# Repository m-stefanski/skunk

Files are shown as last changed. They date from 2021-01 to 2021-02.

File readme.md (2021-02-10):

# Skunks

Skunks (Polish for Skunk) is a small air quality meter aimed for use in developing countries, home projects and in every place where affordable air quality meter might be useful. 

It is designed to be cheap and easy to make from over-the-counter parts.

## Capabilities

Skunk can measure following air parameters:

* PM 2,5
* Temperature
* Humidity
* Pressure

Results are available as a website presented when user connects to a WiFi network the device is broadcasting. It is also possible to configure skunk to connect to any available 2.4 GHz WiFi network and view its results there.

## Hardware

* [WeMOS D1 mini](https://www.wemos.cc/en/latest/d1/d1_mini.html) - for CPU / Memory / IO and WiFi capabilities
* [GP2Y1010AU0F](https://www.sharpsde.com/products/optoelectronic-components/model/GP2Y1010AU0F/) - dust sensor from Sharp
* [BME280](https://www.bosch-sensortec.com/products/environmental-sensors/humidity-sensors-bme280/) - temprerature, humidity and air pressure sensor from BOSH

Data sheets for used components are available in [datasheets](/datasheets) directory.

## Designs

All sources are available in [src](/src) directory. Web content needs to be converted to `.h` files:

```
git clone https://github.com/Jamesits/bin2array.git 
cd ./src/web_content
find . -iname "*.*"  -type f -exec python3 ./../../bin2array/bin2array.py '{}' -O ./../'{}'.h \;
```

BB overview is shown below.

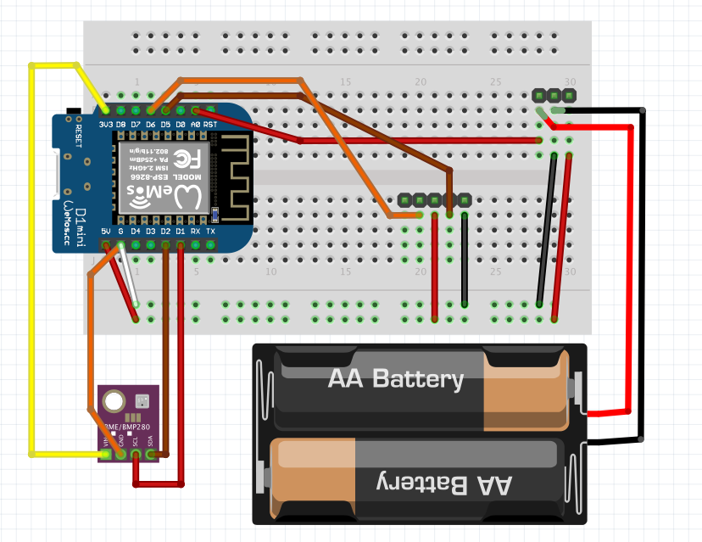
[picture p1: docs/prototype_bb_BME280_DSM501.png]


Electrical schematics:

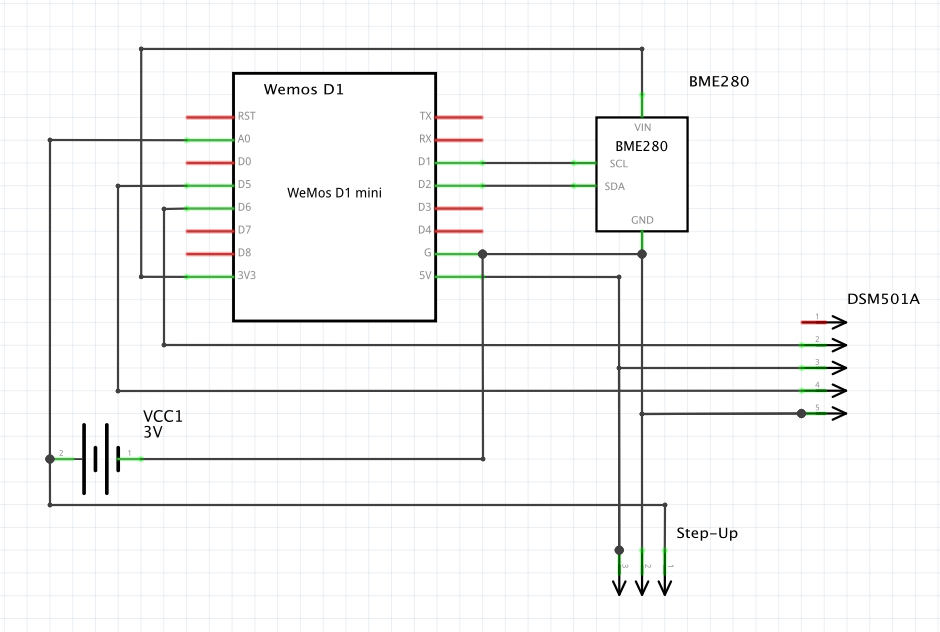
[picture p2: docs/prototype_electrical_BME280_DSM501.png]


PCB:

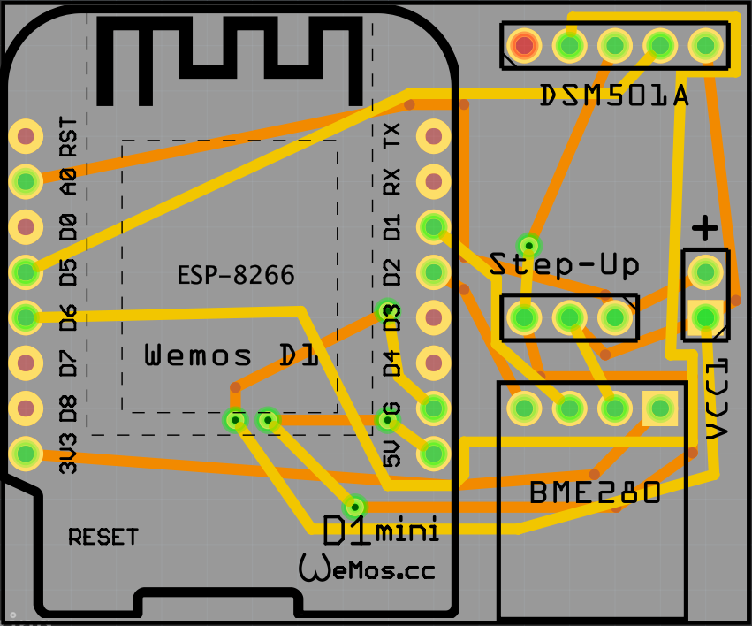
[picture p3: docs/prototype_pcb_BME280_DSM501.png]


And very, VERY unholy real photos of firts prototype:

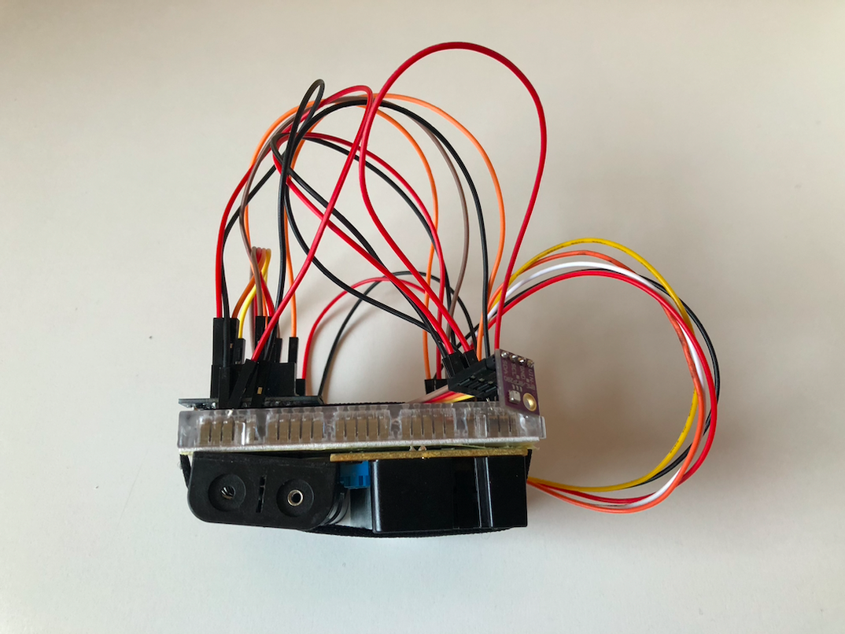
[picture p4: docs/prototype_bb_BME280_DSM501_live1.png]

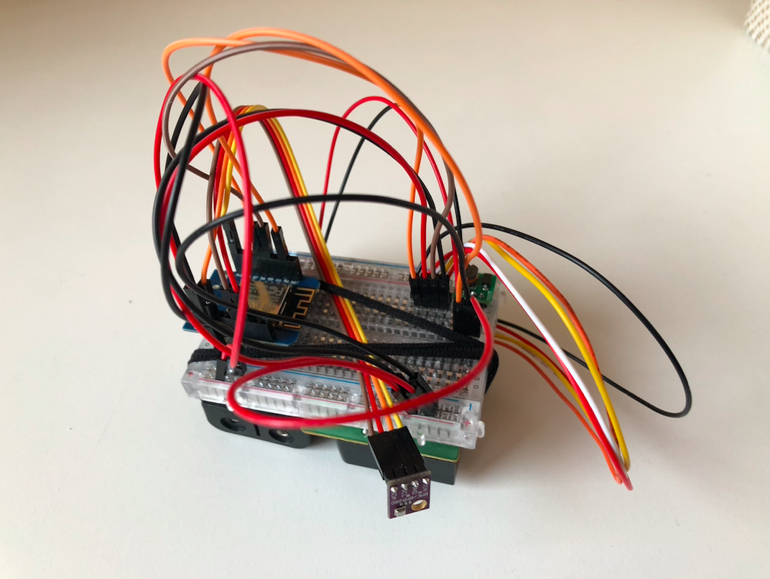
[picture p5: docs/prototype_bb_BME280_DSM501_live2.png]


All hardware designs are stored in [board](/board) directory. Old iterations are kept as well, should the hardware change.

Skunk icon is stored in [icon](/icon) directory. It is a skunk glyph from [OpenMoji](https://openmoji.org) with added background. Due to limited space it is exported as 4-bit grayscale 180x180 px.

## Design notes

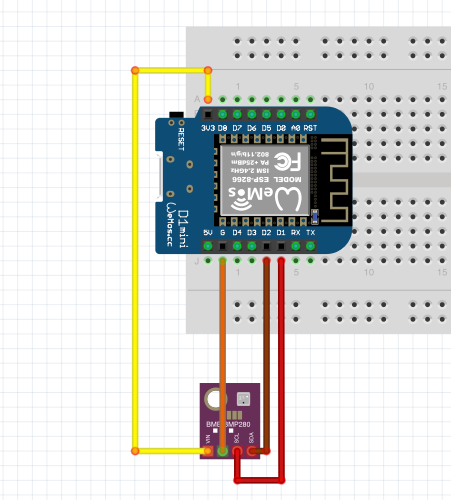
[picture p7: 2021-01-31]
docs/prototype_bb.png

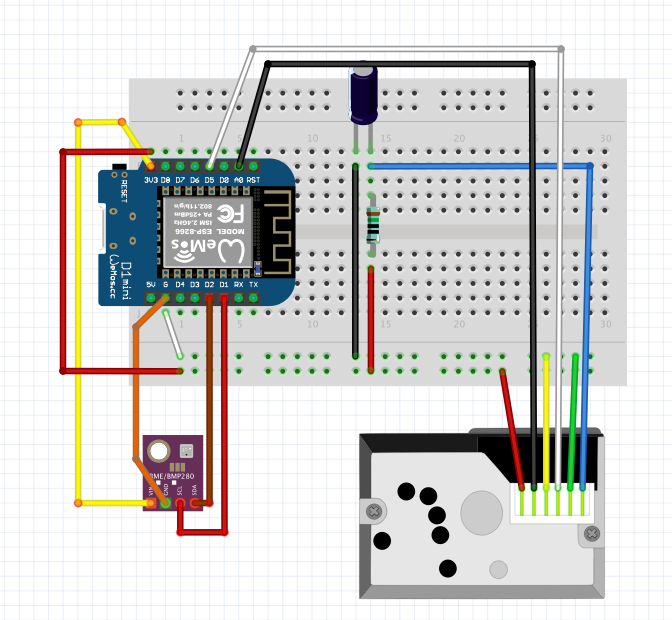
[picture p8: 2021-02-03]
docs/prototype_bb_BME280_GP2Y1010AU0F.png

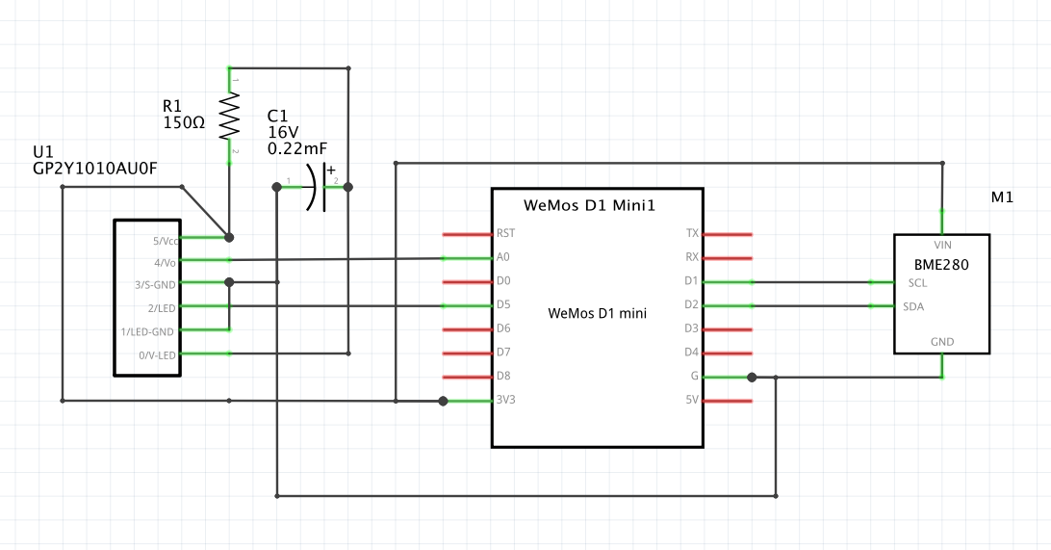
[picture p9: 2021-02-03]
docs/prototype_electrical_BME280_GP2Y1010AU0F.png

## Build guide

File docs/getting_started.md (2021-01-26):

# Running first code

In case of my device (MacOS Big Sur), driver was alread embedded in os, and port was `/dev/cu.usbserial-1420`

To program, esptool was used:

```
sudo pip3 install esptool
sudo esptool.py -p /dev/cu.usbserial-1420 erase_flash
sudo esptool.py -p /dev/cu.usbserial-1420 --baud 460800 write_flash --flash_size=detect 0 ./bin/esp8266-20200911-v1.13.bin
```

To push latest code and run:

```
sudo pip3 install mpy-repl-tool
sudo python3 -m there push ./src/*.py ./ --verbose
sudo python3 -m there -i 
```

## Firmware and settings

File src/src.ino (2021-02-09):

#include <Wire.h>
#include <Adafruit_Sensor.h>
#include <Adafruit_BME280.h>

#include <ESP8266WiFi.h>
#include <DNSServer.h>
#include <ESP8266WebServer.h>
#include "DSM501.h"
#include <Ticker.h>
#include <EEPROM.h>

#define DSM501_PM2_5 D5 // pin 4 - Vout1 - over 2.5 um
#define DSM501_PM1_0 D6 // pin 2 - Vout2 - over 1 um
#define PIN_BATTERY_VOLTAGE A0

#define SAMPLE_TIME_DSM510 30
#define SAMPLE_TIME_BME280 2
#define SAMPLE_TIME_VOLTAGE 1

const char *ssid = "skunks"; // network name
const char *hostname = "skunks"; // dns domain name
IPAddress apIP(192, 168, 4, 1); // ip address

DNSServer dnsServer;
Adafruit_BME280 bme;
DSM501 dsm501;
ESP8266WebServer server(80);
Ticker timer_voltage;
Ticker timer_bme280;

int pm25 = 0;
float battery_voltage = 0;
float temperature = 0;
float humidity = 0;
float pressure = 0;

void setup() {
  Serial.begin(115200);
  cls();
  Serial.println("[app] Starting");
  setup_eeprom(512);
  setup_voltage();
  setup_bme280();
  setup_dsm501a();
  setup_ap();
  setup_dns();
  setup_web();
  Serial.println("[app] Skunks ready");
}

void write_string_to_eeprom(int pos, String str) {
  for (int i = 0; i < str.length(); ++i)
    {
      EEPROM.write(i + pos, str[i]);
    }
  EEPROM.write(str.length(), 0xFF);
  EEPROM.commit();
  Serial.println(String("[eeprom] Wrote ") + str.length() + " bytes from pos: " + pos);
}

String read_string_from_eeprom(int pos) {
  String str;
  int pos_act = pos;
  uint8_t next_char = 0;
  while (true) {
    next_char = EEPROM.read(pos_act);
    if (next_char != 0xFF){
    str += char(next_char);
    pos_act++;
  }
    else {
      Serial.println(String("[eeprom] Read ") + str.length() + " bytes from pos: " + pos + ": " + str);
  return str;
}
  }
}

void loop() {
  server.handleClient();
  dnsServer.processNextRequest();
  read_dsm501a();
}

void cls() {
  Serial.write(27);
  Serial.print("[2J");
  Serial.write(27);
  Serial.print("[H");
}

void setup_eeprom(int size) {
  Serial.println("[eeprom] Initializing ...");
  EEPROM.begin(size);
  delay(50); // without a delay eeprom r/w may result in an error
  Serial.println(String("[eeprom] Initialized size: ") + size);
}

void setup_bme280() {
  Serial.println("[bme280] Setting up...");
  bool status;
  status = bme.begin(0x76);
  if (!status) {
    Serial.println("[bme280] ERROR: device not found!");
    while (1); // stopping the program
  }
  Serial.println("[bme280] Setting repeated measures");
  timer_bme280.attach(SAMPLE_TIME_BME280, read_bme280);
  Serial.println("[bme280] Ready");
}

void setup_dsm501a() {
  Serial.println("[dsm501a] Setting up...");
  dsm501.begin(DSM501_PM1_0, DSM501_PM2_5, SAMPLE_TIME_DSM510);
  Serial.println("[dsm501a] Ready");
}

void setup_voltage() {
  Serial.println("[volt] Setting up...");
  timer_voltage.attach(SAMPLE_TIME_VOLTAGE, read_voltage);
  Serial.println("[volt] Ready");
}

void read_dsm501a(){
  if (dsm501.update())
  { 
    pm25 = dsm501.getConcentration();
    Serial.println(String("[dsm501a] Read: PM1: ") + dsm501.getParticleCount(0) + ", PM2.5: " + dsm501.getParticleCount(1) + ", concentration: " + dsm501.getConcentration());
  } 
}

void read_bme280(){
  temperature = bme.readTemperature();
  pressure = bme.readPressure() / 100.0F;
  humidity = bme.readHumidity();
  Serial.println(String("[bme280] Read: temperature: ") + temperature  + "*C, humidity: " + humidity + "%, pressure: " + pressure + " hPa");
}

void read_voltage() {
  float calculated_voltage = analogRead(PIN_BATTERY_VOLTAGE) / 1024.0F * 3.3;
  battery_voltage = calculated_voltage;
  Serial.println(String("[volt] voltage: ") + battery_voltage + " V");
}

void setup_ap() {
  Serial.println("[wifi] Setting up...");
  WiFi.hostname(hostname);
  WiFi.mode(WIFI_AP);
  WiFi.softAPConfig(apIP, apIP, IPAddress(255, 255, 255, 0));
  WiFi.softAP(ssid);
  IPAddress myIP = WiFi.softAPIP();
  
  Serial.print("[wifi] SSID: ");
  Serial.println(ssid);
  Serial.print("[wifi] IP: ");
  Serial.println(myIP);
}

void setup_dns() {
  Serial.println("[dns] Serring up DNS...");
  dnsServer.setTTL(300);
  dnsServer.setErrorReplyCode(DNSReplyCode::ServerFailure);
  dnsServer.start(53, hostname, apIP);
  Serial.println(String("[dns] create entry for: ") + hostname);
}

void setup_web() {
  Serial.println("[www] Setting up endpoints...");
  server.on("/", handleRoot);
  server.on("/index.html", handleRoot);
  server.on("/style.css", handleCSS);
  server.on("/favicon.png", handleFavicon);
  server.on("/skunk.svg", handleSVGIcon);
  server.on("/cache.manifest", handleCacheM);
  server.on("/sensors/", handleSensors);
  server.begin();
  Serial.println("[www] Server running on port 80");
}

const char index_html[] PROGMEM = { 
  #include "index.html.h" 
  };
void handleRoot() { server.send(200, "text/html", index_html, sizeof(index_html)); }

const char style_css[] PROGMEM = { 
  #include "style.css.h" 
  };
void handleCSS() { server.send(200, "text/css", style_css, sizeof(style_css)); }

const char favicon_png[] PROGMEM = { 
  #include "favicon.png.h" 
  };
void handleFavicon() { server.send(200, "image/png", favicon_png, sizeof(favicon_png)); }

const char skunk_svg[] PROGMEM = { 
  #include "skunk.svg.h" 
  };
void handleSVGIcon() { server.send(200, "image/svg+xml", skunk_svg, sizeof(skunk_svg)); }

const char cache_manifest[] PROGMEM = { 
  #include "cache.manifest.h" 
  };
void handleCacheM() { server.send(200, "text/cache-manifest", cache_manifest, sizeof(cache_manifest)); }

void handleSensors() {
  server.send(
    200, "application/json", 
    String("{\"temperature\": ") + temperature + 
    ", \"pressure\": " + pressure + 
    ", \"humidity\": " + humidity + 
    ", \"uptime\": " + millis() + 
    ", \"voltage\": " + battery_voltage +
    ", \"pm25\": " + pm25 +
    "}");
}

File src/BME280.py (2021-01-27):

# Source: https://github.com/RuiSantosdotme/ESP-MicroPython/blob/master/code/WiFi/HTTP_Client_IFTTT_BME280/BME280.py

from machine import I2C
import time

# BME280 default address.
BME280_I2CADDR = 0x76

# Operating Modes
BME280_OSAMPLE_1 = 1
BME280_OSAMPLE_2 = 2
BME280_OSAMPLE_4 = 3
BME280_OSAMPLE_8 = 4
BME280_OSAMPLE_16 = 5

# BME280 Registers

BME280_REGISTER_DIG_T1 = 0x88  # Trimming parameter registers
BME280_REGISTER_DIG_T2 = 0x8A
BME280_REGISTER_DIG_T3 = 0x8C

BME280_REGISTER_DIG_P1 = 0x8E
BME280_REGISTER_DIG_P2 = 0x90
BME280_REGISTER_DIG_P3 = 0x92
BME280_REGISTER_DIG_P4 = 0x94
BME280_REGISTER_DIG_P5 = 0x96
BME280_REGISTER_DIG_P6 = 0x98
BME280_REGISTER_DIG_P7 = 0x9A
BME280_REGISTER_DIG_P8 = 0x9C
BME280_REGISTER_DIG_P9 = 0x9E

BME280_REGISTER_DIG_H1 = 0xA1
BME280_REGISTER_DIG_H2 = 0xE1
BME280_REGISTER_DIG_H3 = 0xE3
BME280_REGISTER_DIG_H4 = 0xE4
BME280_REGISTER_DIG_H5 = 0xE5
BME280_REGISTER_DIG_H6 = 0xE6
BME280_REGISTER_DIG_H7 = 0xE7

BME280_REGISTER_CHIPID = 0xD0
BME280_REGISTER_VERSION = 0xD1
BME280_REGISTER_SOFTRESET = 0xE0

BME280_REGISTER_CONTROL_HUM = 0xF2
BME280_REGISTER_CONTROL = 0xF4
BME280_REGISTER_CONFIG = 0xF5
BME280_REGISTER_PRESSURE_DATA = 0xF7
BME280_REGISTER_TEMP_DATA = 0xFA
BME280_REGISTER_HUMIDITY_DATA = 0xFD


class Device:
  """Class for communicating with an I2C device.

  Allows reading and writing 8-bit, 16-bit, and byte array values to
  registers on the device."""

  def __init__(self, address, i2c):
    """Create an instance of the I2C device at the specified address using
    the specified I2C interface object."""
    self._address = address
    self._i2c = i2c

  def writeRaw8(self, value):
    """Write an 8-bit value on the bus (without register)."""
    value = value & 0xFF
    self._i2c.writeto(self._address, value)

  def write8(self, register, value):
    """Write an 8-bit value to the specified register."""
    b=bytearray(1)
    b[0]=value & 0xFF
    self._i2c.writeto_mem(self._address, register, b)

  def write16(self, register, value):
    """Write a 16-bit value to the specified register."""
    value = value & 0xFFFF
    b=bytearray(2)
    b[0]= value & 0xFF
    b[1]= (value>>8) & 0xFF
    self.i2c.writeto_mem(self._address, register, value)

  def readRaw8(self):
    """Read an 8-bit value on the bus (without register)."""
    return int.from_bytes(self._i2c.readfrom(self._address, 1),'little') & 0xFF

  def readU8(self, register):
    """Read an unsigned byte from the specified register."""
    return int.from_bytes(
        self._i2c.readfrom_mem(self._address, register, 1),'little') & 0xFF

  def readS8(self, register):
    """Read a signed byte from the specified register."""
    result = self.readU8(register)
    if result > 127:
      result -= 256
    return result

  def readU16(self, register, little_endian=True):
    """Read an unsigned 16-bit value from the specified register, with the
    specified endianness (default little endian, or least significant byte
    first)."""
    result = int.from_bytes(
        self._i2c.readfrom_mem(self._address, register, 2),'little') & 0xFFFF
    if not little_endian:
      result = ((result << 8) & 0xFF00) + (result >> 8)
    return result

  def readS16(self, register, little_endian=True):
    """Read a signed 16-bit value from the specified register, with the
    specified endianness (default little endian, or least significant byte
    first)."""
    result = self.readU16(register, little_endian)
    if result > 32767:
      result -= 65536
    return result

  def readU16LE(self, register):
    """Read an unsigned 16-bit value from the specified register, in little
    endian byte order."""
    return self.readU16(register, little_endian=True)

  def readU16BE(self, register):
    """Read an unsigned 16-bit value from the specified register, in big
    endian byte order."""
    return self.readU16(register, little_endian=False)

  def readS16LE(self, register):
    """Read a signed 16-bit value from the specified register, in little
    endian byte order."""
    return self.readS16(register, little_endian=True)

  def readS16BE(self, register):
    """Read a signed 16-bit value from the specified register, in big
    endian byte order."""
    return self.readS16(register, little_endian=False)


class BME280:
  def __init__(self, mode=BME280_OSAMPLE_1, address=BME280_I2CADDR, i2c=None,
               **kwargs):
    # Check that mode is valid.
    if mode not in [BME280_OSAMPLE_1, BME280_OSAMPLE_2, BME280_OSAMPLE_4,
                    BME280_OSAMPLE_8, BME280_OSAMPLE_16]:
        raise ValueError(
            'Unexpected mode value {0}. Set mode to one of '
            'BME280_ULTRALOWPOWER, BME280_STANDARD, BME280_HIGHRES, or '
            'BME280_ULTRAHIGHRES'.format(mode))
    self._mode = mode
    # Create I2C device.
    if i2c is None:
      raise ValueError('An I2C object is required.')
    self._device = Device(address, i2c)
    # Load calibration values.
    self._load_calibration()
    self._device.write8(BME280_REGISTER_CONTROL, 0x3F)
    self.t_fine = 0

  def _load_calibration(self):

    self.dig_T1 = self._device.readU16LE(BME280_REGISTER_DIG_T1)
    self.dig_T2 = self._device.readS16LE(BME280_REGISTER_DIG_T2)
    self.dig_T3 = self._device.readS16LE(BME280_REGISTER_DIG_T3)

    self.dig_P1 = self._device.readU16LE(BME280_REGISTER_DIG_P1)
    self.dig_P2 = self._device.readS16LE(BME280_REGISTER_DIG_P2)
    self.dig_P3 = self._device.readS16LE(BME280_REGISTER_DIG_P3)
    self.dig_P4 = self._device.readS16LE(BME280_REGISTER_DIG_P4)
    self.dig_P5 = self._device.readS16LE(BME280_REGISTER_DIG_P5)
    self.dig_P6 = self._device.readS16LE(BME280_REGISTER_DIG_P6)
    self.dig_P7 = self._device.readS16LE(BME280_REGISTER_DIG_P7)
    self.dig_P8 = self._device.readS16LE(BME280_REGISTER_DIG_P8)
    self.dig_P9 = self._device.readS16LE(BME280_REGISTER_DIG_P9)

    self.dig_H1 = self._device.readU8(BME280_REGISTER_DIG_H1)
    self.dig_H2 = self._device.readS16LE(BME280_REGISTER_DIG_H2)
    self.dig_H3 = self._device.readU8(BME280_REGISTER_DIG_H3)
    self.dig_H6 = self._device.readS8(BME280_REGISTER_DIG_H7)

    h4 = self._device.readS8(BME280_REGISTER_DIG_H4)
    h4 = (h4 << 24) >> 20
    self.dig_H4 = h4 | (self._device.readU8(BME280_REGISTER_DIG_H5) & 0x0F)

    h5 = self._device.readS8(BME280_REGISTER_DIG_H6)
    h5 = (h5 << 24) >> 20
    self.dig_H5 = h5 | (
        self._device.readU8(BME280_REGISTER_DIG_H5) >> 4 & 0x0F)

  def read_raw_temp(self):
    """Reads the raw (uncompensated) temperature from the sensor."""
    meas = self._mode
    self._device.write8(BME280_REGISTER_CONTROL_HUM, meas)
    meas = self._mode << 5 | self._mode << 2 | 1
    self._device.write8(BME280_REGISTER_CONTROL, meas)
    sleep_time = 1250 + 2300 * (1 << self._mode)
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

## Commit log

2021-01-25 initial commit - first design of breadboard
    [prototype_1.fzz]
2021-01-26 reading temperature in cycle added
2021-01-27 updated python3 in prerequisites to board flashing
2021-01-31 feat: rewrite to C due to memory constrains
    [prototype.fzz, prototype_1.fzz]
2021-01-31 fix: incorrect board image reference
2021-02-01 feat: logo compatible with old android devices
2021-02-02 feat: missing schematics board elements
2021-02-03 fix: incorrect pm25 calculation (still WIP)
    [src.ino]
2021-02-03 feat: board + readme updated adding GP2Y1010AU0F
    [prototype_BME280.fzz, prototype_BME280_GP2Y1010AU0F.fzz]
2021-02-03 feat: electrical diagram added
    [prototype_GP2Y1010AU0F.fzz]
2021-02-03 feat: PCB routed
    [prototype_GP2Y1010AU0F.fzz]
2021-02-03 feat: PCB diagram updated
    [prototype_BME280_GP2Y1010AU0F.fzz, prototype_GP2Y1010AU0F.fzz]
2021-02-04 feat: battery meter in, Bosh dust out
2021-02-07 feat: battery read triggered by timer
2021-02-08 fix: incorrect voltage calculation causing 0V shown
    [src.ino]
2021-02-08 fix: log messages in eeprom functions
    [src.ino]
2021-02-09 fix: EEPROM strings now FF-terminated
    [src.ino]
2021-02-10 feat: DSM501 shematics added
    [prototype_BME280_DSM501.fzz]
2021-02-10 feat: live prototype bb photos attached
2021-02-10 fix: step-up converter pinout inverted
    [prototype_BME280_DSM501.fzz]
